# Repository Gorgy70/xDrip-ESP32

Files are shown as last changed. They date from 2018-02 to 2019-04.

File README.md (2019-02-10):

# xDrip-ESP32
Проект с функциональностью wixel-xDrip, xBridge2 и Parakeet на контроллере ESP32<br>
<br>

Данный проект является развитием проекта Parakeet-A (https://github.com/Gorgy70/parakeet-A) и основан на следующих проектах:<br>
1. Parakeet от Jamorham (https://jamorham.github.io, https://github.com/jamorham/wixel-xDrip)<br>
2. XDrip от Emma Black (http://stephenblackwasalreadytaken.github.io/xDrip, https://github.com/StephenBlackWasAlreadyTaken/xDrip)<br>
3. CC2500-Project от Don Browne (https://github.com/brownedon/CC2500-Project)<br>
<br>
<br>
<b>Сборка прибора:</b><br>
<br>
Для сборки прибора необходимы следующие компоненты:<br>
1. Контроллер ESP-32. <br>
Я использую модуль ESP32-WROOM:<br>
https://www.aliexpress.com/item/ESP-32S-ESP-WROOM-32-ESP32-ESP-32-Bluetooth-and-WIFI-Dual-Core-CPU-with-Low/32826634234.html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
<br>
2. Радиомодуль на базе чипа Texas Instruments CC2500 с усилителем слабого сигнала.<br>
https://www.aliexpress.com/item/CC2500-PA-LNA-Romote-Wireless-Module-CC2500-SI4432-For-RC-Quadcopter-Helicopter-Multirotor-Model-Parts/32740098548.html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
<br>
3. Модуль контроля заряда батареи.<br>
4. Аккумулятор 3.7 В.<br>
5. Стаблизатор, для понижения напряжения до 3.3В:
https://www.aliexpress.com/item/Free-Shipping-Hot-Sale-Smart-Electronics-Integrated-Circuit-AP7361-15FGE-7-IC-REG-LDO-1-5V/32584383940.html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
<br>
6. Светодиоды, резисторы и конденсаторы в соответствии с печатной платой.<br>
<br>
<b>Установка поддержки ESP-32 в Arduino Studio:</b><br>
<br>
https://github.com/espressif/arduino-esp32/blob/master/docs/arduino-ide/windows.md<br>
<br>
<b>Настройка библиотеки ESP32</b><br>
<br>
При использовании свежих версий SDK тактовая частота контроллера устанавливается в Arduino IDE.
Также необходимо установить параметр "Partition Scheme" в значение "No OTA (Large APP)". В противном случае компиляция скэтча завершится с ошибкой.
<br>
<b>Загрузка прошивки в контроллер</b><br>
<br>
Для загрузки прошивки в контроллер необходимо подключить к плате адаптер USB-TTL используя контакты для программирования<br>
Чтобы активировать режим прошивки контроллера необходимо замкнуть контакт IO0 контроллера на землю и перегрузить контроллер кратковременным замыканием контакта EN на землю.<br>
Если не удается загрузит прошивку на скорости 921600 - попробуйте понизить скорость до 115200.<br>
После удачной загрузки прошивки убрать перемычку с контакта IO0 на землю и перегрузить контроллер.<br>
<br>
<br>
<b>Настройка прибора:</b><br>
<br>
Первые 2 минуты после включения прибор находится в режиме настройки.<br>
В этом режиме прибор запускает WiFi точку доступа c именем "Parakeet" и без пароля.<br>
Для конфигурации прибора необходимо подключиться к этой точке доступа, запустить интернет браузер и в адресной строке ввести адрес http://192.168.70.1<br>
В открывшейся форме параметров можно настроить следующие параметры:<br>
<ul style="list-style-type:disc">
  <li>Код трансмиттера Dexcom</li>
  <li>Цифровой код для работы с облачным сервисом</li>
  <li>Адрес облачного сервиса</li>
  <li>Имя точки доступа WiFi для передачи данных в интернет. Если вы не планируете использовать WiFi оставьте это поле пустым.</li>
  <li>Пароль для точки доступа WiFi</li>
  <li>Формат обмена по BlueTooth (без BlueTooth, xDrip, xBridge)</li>
  <li>Признак работы прибора с мобильной сетью</li>
  <li>APN вышего мобильного оператора</li>
</ul>
После заполнения всех необходимых полей нажмите кнопку "Save".<br>
В случае использования прибора в режиме xBridge код трансмиттера Dexcom можно установить с помощью программы xDrip+ на вашем мобильном телефоне.<br>
В случае использования прибора с поддержкой мобильной сети, некоторые настройки можно изменять с помощью СМС на номер симкарты, установленной в прибор.<br>
Список обрабатываемых СМС:<br>
<ul style="list-style-type:disc">
  <li>TRANSMIT <Код трансмиттера Dexcom> - установить код трансмиттера Dexcom</li>
  <li>PWD <цифровой код> - установить цифровой код</li>
  <li>HTTP <адрес облачного сервиса> - установить адрес облачного сервиса</li>
  <li>APN <APN вашего мобильного оператора> - установить APN мобильного оператора</li>
  <li>SETTINGS - узнать текущие настройки. Текущие настройки будут присланы несколькими СМС-сообщениями</li>
  <li>REBOOT - перегрузить прибор</li>
  <li>VERSION - узнать версию прошивки</li>
  <li>USE_GSM <флаг>- включить/выключить мобильную связь. В качестве флага могут использоваться символы 0,N,n для выключения мобильной связи и символы 1,Y,y для включения.
Следует заметить, что при выключенной мобильной связи прибор не сможет принять СМС.</li>
  <li>BT_FORMAT <флаг> - установка формата обмена данными по BlueTooth. Возможные значения флага: 0,N,n - без BlueTooth; 1,D,d - xDrip; 2,B,b - xBridge</li>
</ul>
<br>
<b>Привязка прибора к программе xDrip+ по протоколу BlueTooth:</b><br>
<br>
Алгоритм работы прибора разработан таким образом, что BlueTooth включается только после того как прибор поймает сигнал от трансмиттера.<br>
Для привязки прибора к программе xDrip+ по протоколу BlueTooth необходимо выполнить следующие действия:<br>
1. Включить прибор.<br>
2. При необходимости настроить параметры прибора<br>
3. Дождаться сигнала с трансмиттера. Во время ожидания сигнала с трансмиттера прибор коротко мигает желтым светодиодом.<br>
4. После пойманного сигнала, прибор отправит данные в интернет (если такой режим работы настроен) и будет ждать 45 секунд соединения с программой xDrip+
по протоколу BlueTooth. При этом будет непрерывно гореть желтый светодиод.<br>
5. В течении 45 секунд в программе xDrip+  необходимо произвести BlueTooth Scan и выбрать прибор из списка найденных.<br>

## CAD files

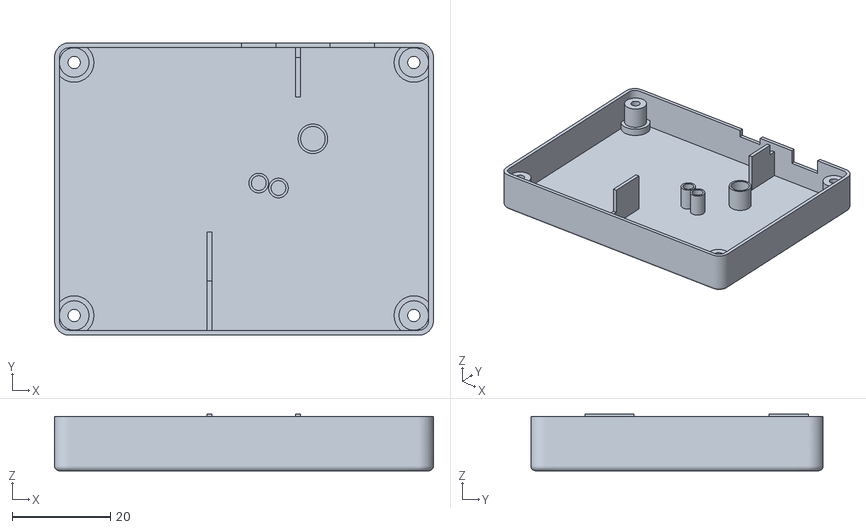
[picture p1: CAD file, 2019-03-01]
xDrip32-3G-Top4.stl
77.0 x 59.4 x 11.5

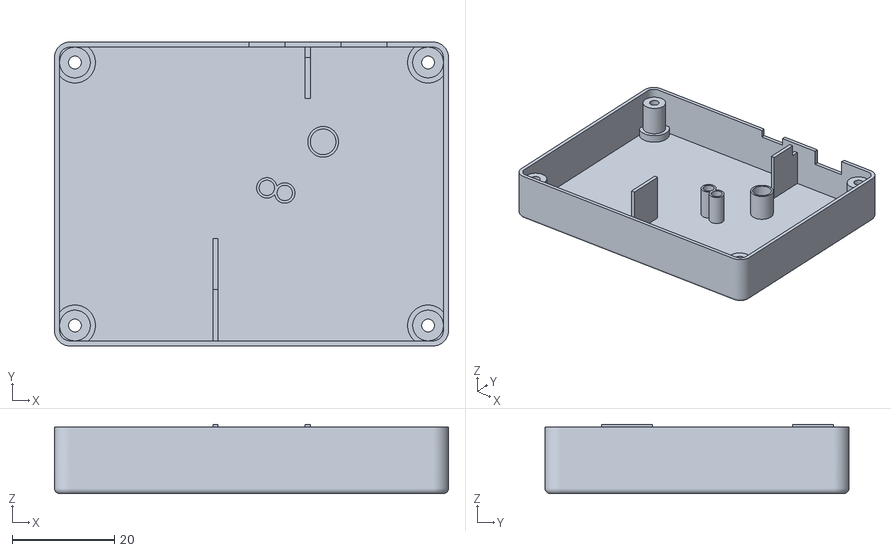
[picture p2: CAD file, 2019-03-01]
xDrip32-3G-Top5.stl
77.0 x 59.4 x 13.5

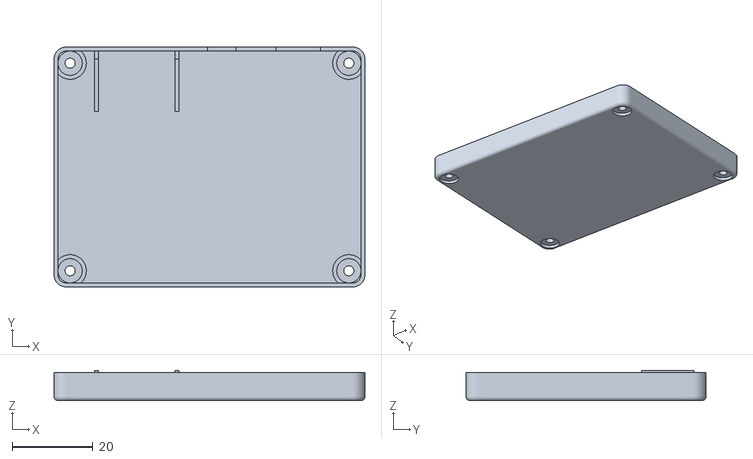
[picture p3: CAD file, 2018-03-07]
xDrip32-WiFi-Top2.stl
77.0 x 59.4 x 7.50

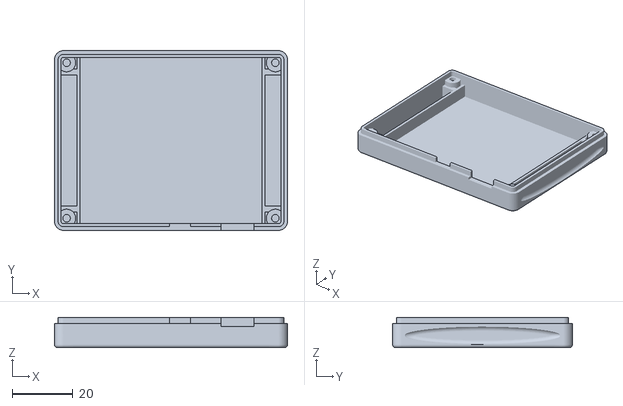
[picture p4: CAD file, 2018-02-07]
xDrip32-WiFi-Bottom3.stl
77.0 x 59.4 x 10.00

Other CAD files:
xDrip32-3G-Bottom3.stl

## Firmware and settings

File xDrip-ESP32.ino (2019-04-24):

 
#define DEBUG
//#define INT_BLINK_LED
#define EXT_BLINK_LED
#define GSM_MODEM
//#define MODEM_SLEEP_DTR
//#define PCB_V1
//#define PCB_V2
#define PCB_V3
//#define USE_FREQEST    
#define DEEP_SLEEP_MODE
#define BT_PAIRING 

#include "driver/gpio.h"
#include "soc/rtc_cntl_reg.h"
#include "driver/rtc_cntl.h"
#include "soc/rtc.h"
#include "rom/rtc.h"
#include "SPI.h"
#include "EEPROM.h"
#include "WiFi.h"
#include "HTTPClient.h"
#include "bt.h"
#include "nvs_flash.h"
#include <WebServer.h>
//#include <BLEDevice.h>
//#include <BLEServer.h>
//#include <BLEUtils.h>
//#include <BLE2902.h>
//#include "bta_api.h"

#include "esp_system.h"
#include "esp_wifi.h"
#include "esp_wifi_types.h"
#include "esp_gap_ble_api.h"
#include "esp_gatts_api.h"
#include "esp_bt_defs.h"
#include "esp_bt_main.h"
#include "esp_sleep.h"
#include "esp_deep_sleep.h"

#include "cc2500_REG.h"
#include "webform.h"

extern "C" {
uint8_t temprature_sens_read(); 
}

#define VERSION_NUM "1.6.3"

#define LEN_PIN    GPIO_NUM_5             // Цифровой канал, к которму подключен контакт LEN (усилитель слабого сигнала) платы CC2500 (Предыдущее значение 17).
#define BAT_PIN    GPIO_NUM_34            // Аналоговый канал для измерения напряжения питания
#ifdef EXT_BLINK_LED
  #define RED_LED_PIN    GPIO_NUM_16
  #define YELLOW_LED_PIN GPIO_NUM_17
#endif

#define SCK_PIN   GPIO_NUM_22
#define MISO_PIN  GPIO_NUM_21
#define MOSI_PIN  GPIO_NUM_23
#define SS_PIN    GPIO_NUM_18 // Предыдущее значение 5
#ifdef PCB_V1
  #define GDO0_PIN   GPIO_NUM_19            // Цифровой канал, к которму подключен контакт GD0 платы CC2500
#endif
#ifdef PCB_V2
  #define GDO0_PIN   GPIO_NUM_19            // Цифровой канал, к которму подключен контакт GD0 платы CC2500
#endif
#ifdef PCB_V3
  #define GDO0_PIN   GPIO_NUM_15            // Цифровой канал, к которму подключен контакт GD0 платы CC2500
#endif
#ifdef GSM_MODEM
  #define RX_PIN  GPIO_NUM_25
  #define TX_PIN  GPIO_NUM_26
#ifdef PCB_V1
  #define DTR_PIN    GPIO_NUM_13
#endif
#ifdef PCB_V2
  #define DTR_PIN    GPIO_NUM_14
#endif
#ifdef PCB_V3
  #define DTR_PIN    GPIO_NUM_14
#endif
  #define RST_PIN    GPIO_NUM_27
#endif

#define NUM_CHANNELS        (4)       // Кол-во проверяемых каналов
#define FIVE_MINUTE         300000    // 5 минут
#define TWO_MINUTE          120000    // 2 минуты
#define WAKEUP_BT_TIME      54000     // Время необходимое для просыпания прибора c BT
#define WAKEUP_NON_BT_TIME  5000      // Время необходимое для просыпания прибора без BT
#define SPI_TIME_OUT        1000

#define RADIO_BUFFER_LEN 200 // Размер буфера для приема данных от радиомодуля
#ifdef GSM_MODEM
  #define SERIAL_BUFFER_LEN 200 // Размер буфера для приема данных от GSM модема
#endif

#define GSM_DELAY 200         // Задержка между командами модема

// assuming that there is a 10k ohm resistor between BAT+ and BAT_PIN, and a 27k ohm resistor between BAT_PIN and GND
#define  VREF                 3.3 // Опорное напряжение для аналогового входа
#define  VMAX                 4.2  // Максимальное напряжение батареи
#ifdef GSM_MODEM
#define  VMIN                 3.2  // Минимальное напряжение батареи при использовании ГСМ модема
#else
#define  VMIN                 3.0  // Минимальное напряжение батареи
#endif
#define  R1                   10   // Резистор делителя напряжения между BAT+ и BAT_PIN (кОм)
#define  R2                   27   // Резистор делителя напряжения между BAT_PIN и GND (кОм)
#define  ANALOG_RESOLUTION    4095 // Масимальное значение на аналоговом входе. Ио умолчанию 12 бит 
int      BATTERY_MAXIMUM  =   VMAX*ANALOG_RESOLUTION*R2/(R1+R2)/VREF ; //950 4.2V 1023*4.2*27(27+10)/3.3
int      BATTERY_MINIMUM  =   VMIN*ANALOG_RESOLUTION*R2/(R1+R2)/VREF ; //678 3.0V 1023*3.0*27/(27+10)/3.3

#define my_webservice_url    "http://parakeet.esen.ru/receiver.cgi"
#define my_webservice_reply  "!ACK"
#define my_user_agent        "parakeet-ESP32"
#define my_password_code     "12543"
#define my_gprs_apn   "internet.mts.ru"

#define my_wifi_ssid         "ssid"
#define my_wifi_pwd          "password"

#define GATTS_SERVICE_UUID_XDRIP     0xFFE0  // UID сервиса BLE
#define GATTS_CHAR_UUID_XDRIP        0xFFE1  // UID значения BLE
#define GATTS_NUM_HANDLE_TEST_ON     4     
#define SERVICE_UUID_XDRIP = "0000ffe0-0000-1000-8000-00805f9b34fb";
#define CHAR_UUID_XDRIP = "0000ffe1-0000-1000-8000-00805f9b34fb";
  
/* maximum value of a characteristic */
#define GATTS_CHAR_VAL_LEN_MAX 0xFF

// defines the xBridge protocol functional level.  Sent in each packet as the last byte.
#define DEXBRIDGE_PROTO_LEVEL (0x01)

portMUX_TYPE mux = portMUX_INITIALIZER_UNLOCKED;

unsigned long dex_tx_id;
char transmitter_id[] = "ABCDE";

IPAddress local_IP(192,168,70,1);
IPAddress gateway(192,168,70,1);
IPAddress subnet(255,255,255,0);
uint8_t   wifi_mac[6];

//WiFiServer server(80);
//WiFiClient client;
WebServer server2(80);


SPIClass SPIclient(VSPI);

#ifdef GSM_MODEM
  #define ERROR_STR "ERROR"
//  SoftwareSerial mySerial(RX_PIN, TX_PIN); // RX, TX
  HardwareSerial mySerial(2);
#endif
  
unsigned long web_server_start_time;

unsigned long packet_received = 0;
unsigned long cc2500_start_time;
int current_channel;
boolean packet_catched;
boolean len_pin_low;
volatile byte gdo0_status;
byte loop_count;
volatile boolean new_dex_id_recieved;
volatile boolean ack_recieved;
volatile boolean ble_connected;

#ifdef USE_FREQEST
RTC_DATA_ATTR byte fOffset[NUM_CHANNELS] = { 0x00, 0x00, 0x00, 0x00 };
#else
byte fOffset[NUM_CHANNELS] = { 0xE4, 0xE3, 0xE2, 0xE2 };
#endif
byte nChannels[NUM_CHANNELS] = { 0, 100, 199, 209 };
unsigned long waitTimes[NUM_CHANNELS] = { 0, 550, 550, 550 };
char version_str[15];

byte sequential_missed_packets = 0;
byte wait_after_time = 100;
unsigned long next_time = 0; // Время ожидания следующего пакета на канале 0
unsigned long catch_time = 0; // Время последнего пойманного пакета (приведенное к пакету на канале 0)

byte misses_until_failure = 2;                                                   //
// after how many missed packets should we just start a nonstop scan?                               //
// a high value is better for conserving batter life if you go out of wixel range a lot             //
// but it could also mean missing packets for MUCH longer periods of time                           //
// a value of zero is best if you dont care at all about battery life                               //

byte wifi_wait_tyme = 100; // Время ожидания соединения WiFi в секундах
byte default_bt_format = 0; // Формат обмена по протколу BlueTooth 0 - None 1 - xDrip, 2 - xBridge
unsigned int battery_milivolts;
int battery_percent;
boolean low_battery = false;
unsigned int wake_up_time; // За сколько времени до ожидаемого сигнала надо проснуться

#ifdef GSM_MODEM
  boolean gsm_availible = false; // Доступность связи GSM
  boolean modem_availible = false; // Доступность модема на порту
  boolean internet_availible = false; // Флаг подключения мобильного интернета
  boolean modem_sleeping = false; // Модем находится в режиме сна
  char SerialBuffer[SERIAL_BUFFER_LEN]; // Буффер для работы GSM модемом
#endif

char radio_buff[RADIO_BUFFER_LEN]; // Буффер для чтения данных и прочих нужд

volatile uint16_t ble_gatts_if = ESP_GATT_IF_NONE;
uint16_t ble_conn_id;
uint16_t ble_attr_handle;

esp_gatt_srvc_id_t ble_service;
esp_bt_uuid_t ble_character;
esp_bt_uuid_t ble_descr_uuid;

// Коды ошибок мигают лампочкой в двоичной системе
// 1 (0001) - Нет модключения к WiFi
// 2 (0010) - Облачная служба не отвечает
// 3 (0011) - Облачная служба возвращает ошибку
// 4 (0100) - Неверный CRC в сохраненных настройках. Берем настройки по умолчанию
// 5 (0101) - Не подключен модем.
// 6 (0110) - Нет мобильной связи
// 7 (0111) - Нет мобильного интернета

/* value range of a attribute (characteristic) */
uint8_t attr_str[] = {0x00};
esp_attr_value_t gatts_attr_val =
{
    .attr_max_len = GATTS_CHAR_VAL_LEN_MAX,
    .attr_len     = sizeof(attr_str),
    .attr_value   = attr_str,
};

/* service uuid */
static uint8_t service_uuid128[32] = {
    /* LSB <--------------------------------------------------------------------------------> MSB */
    //first uuid, 16bit, [12],[13] is the value
    0xfb, 0x34, 0x9b, 0x5f, 0x80, 0x00, 0x00, 0x80, 0x00, 0x10, 0x00, 0x00, 0xAB, 0xCD, 0x00, 0x00,
};

static esp_ble_adv_data_t ble_adv_data = {
    .set_scan_rsp = false,
    .include_name = true,
    .include_txpower = true,
    .min_interval = 0x20,
    .max_interval = 0x40,
    .appearance = 0x00,
    .manufacturer_len = 0,
    .p_manufacturer_data =  NULL,
    .service_data_len = 0,
    .p_service_data = NULL,
    .service_uuid_len = 16,
    .p_service_uuid = service_uuid128,
    .flag = (ESP_BLE_ADV_FLAG_GEN_DISC | ESP_BLE_ADV_FLAG_BREDR_NOT_SPT),
};

esp_ble_adv_params_t ble_adv_params;


typedef struct _Dexcom_packet
{
  byte len;
  unsigned long dest_addr;
  unsigned long src_addr;
  byte port;
  byte device_info;
  byte txId;
  unsigned int raw;
  unsigned int filtered;
  byte battery;
  byte unknown;
  byte checksum;
  byte RSSI;
  byte LQI2;
} Dexcom_packet;

Dexcom_packet Pkt;

typedef struct _RawRecord
{
  byte size; //size of the packet.
  byte cmd_code; // code for this data packet.  Always 00 for a Dexcom data packet.
  unsigned long  raw;  //"raw" BGL value.
  unsigned long  filtered; //"filtered" BGL value 
  byte dex_battery;  //battery value
  byte my_battery; //xBridge battery value
  unsigned long  dex_src_id;   //raw TXID of the Dexcom Transmitter
  //int8  RSSI; //RSSI level of the transmitter, used to determine if it is in range.
  //uint8 txid; //ID of this transmission.  Essentially a sequence from 0-63
  byte function; // Byte representing the xBridge code funcitonality.  01 = this level.
} RawRecord;

typedef struct _parakeet_settings
{
  unsigned long dex_tx_id;     //4 bytes
  char http_url[56];
  char password_code[6];
  char wifi_ssid[17];
  char wifi_pwd[18];
  byte bt_format;
  byte use_gsm;
  char gsm_apn[31];
  unsigned long checksum; // needs to be aligned

} parakeet_settings;

parakeet_settings settings;

typedef struct _bad_data_element
{
  boolean has_data;
  char    data[21];
} bad_data_element;

bad_data_element bad_data[NUM_CHANNELS];

char SrcNameTable[32] = { '0', '1', '2', '3', '4', '5', '6', '7',
                          '8', '9', 'A', 'B', 'C', 'D', 'E', 'F',
                          'G', 'H', 'J', 'K', 'L', 'M', 'N', 'P',
                          'Q', 'R', 'S', 'T', 'U', 'W', 'X', 'Y'
                        };


void dexcom_src_to_ascii(unsigned long src, char addr[6]) {
  addr[0] = SrcNameTable[(src >> 20) & 0x1F];
  addr[1] = SrcNameTable[(src >> 15) & 0x1F];
  addr[2] = SrcNameTable[(src >> 10) & 0x1F];
  addr[3] = SrcNameTable[(src >> 5) & 0x1F];
  addr[4] = SrcNameTable[(src >> 0) & 0x1F];
  addr[5] = 0;
}


unsigned long getSrcValue(char srcVal) {
  byte i = 0;
  for (i = 0; i < 32; i++) {
    if (SrcNameTable[i] == srcVal) break;
  }
  return i & 0xFF;
}

unsigned long asciiToDexcomSrc(char addr[6]) {
  unsigned long src = 0;
  src |= (getSrcValue(addr[0]) << 20);
  src |= (getSrcValue(addr[1]) << 15);
  src |= (getSrcValue(addr[2]) << 10);
  src |= (getSrcValue(addr[3]) << 5);
  src |= getSrcValue(addr[4]);
  return src;
}

byte bit_reverse_byte (byte in)
{
    byte bRet = 0;
    if (in & 0x01)
        bRet |= 0x80;
    if (in & 0x02)
        bRet |= 0x40;
    if (in & 0x04)
        bRet |= 0x20;
    if (in & 0x08)
        bRet |= 0x10;
    if (in & 0x10)
        bRet |= 0x08;
    if (in & 0x20)
        bRet |= 0x04;
    if (in & 0x40)
        bRet |= 0x02;
    if (in & 0x80)
        bRet |= 0x01;
    return bRet;
}

void bit_reverse_bytes (byte * buf, byte nLen)
{
    byte i = 0;
    for (; i < nLen; i++)
    {
        buf[i] = bit_reverse_byte (buf[i]);
    }
}

unsigned long dex_num_decoder (unsigned int usShortFloat)
{
    unsigned int usReversed = usShortFloat;
    byte usExponent = 0;
    unsigned long usMantissa = 0;
    bit_reverse_bytes ((byte *) & usReversed, 2);
    usExponent = ((usReversed & 0xE000) >> 13);
    usMantissa = (usReversed & 0x1FFF);
    return usMantissa << usExponent;
}

void clearSettings()
{
  memset (&settings, 0, sizeof (settings));
  settings.dex_tx_id = asciiToDexcomSrc (transmitter_id);
  dex_tx_id = settings.dex_tx_id;
  sprintf(settings.http_url, my_webservice_url);
  sprintf(settings.password_code, my_password_code);
  sprintf(settings.wifi_ssid, my_wifi_ssid);
  sprintf(settings.wifi_pwd, my_wifi_pwd);
  sprintf(settings.gsm_apn, my_gprs_apn);
  settings.bt_format = default_bt_format;
  settings.checksum = 0;
}

unsigned long checksum_settings()
{
  char* flash_pointer;
  unsigned long chk = 0x12345678;
  byte i;
  //   flash_pointer = (char*)settings;
  flash_pointer = (char*)&settings;
  for (i = 0; i < sizeof(parakeet_settings) - 4; i++)
  {
    chk += (flash_pointer[i] * (i + 1));
    chk++;
  }
  return chk;
}

void saveSettingsToFlash()
{
  char* flash_pointer;
  byte i;

  EEPROM.begin(sizeof(parakeet_settings));
  
  settings.checksum = checksum_settings();
  flash_pointer = (char*)&settings;
  for (i = 0; i < sizeof(parakeet_settings); i++)
  {
    EEPROM.write(i,flash_pointer[i]);
  }
  EEPROM.commit();
//  EEPROM.put(0, settings);
}

void loadSettingsFromFlash()
{
  char* flash_pointer;
  byte i;

  EEPROM.begin(sizeof(parakeet_settings));
  flash_pointer = (char*)&settings;
  for (i = 0; i < sizeof(parakeet_settings); i++)
  {
    flash_pointer[i] = EEPROM.read(i);
  }
  
//  EEPROM.get(0, settings);
  dex_tx_id = settings.dex_tx_id;
  if (settings.checksum != checksum_settings()) {
    clearSettings();
#ifdef INT_BLINK_LED
    blink_sequence("0100");
#endif
#ifdef EXT_BLINK_LED
    blink_sequence_red("0100");
#endif
  }
}

#ifdef EXT_BLINK_LED
void blink_sequence_red(const char *sequence) {
  byte i;

  digitalWrite(YELLOW_LED_PIN, HIGH);
  digitalWrite(RED_LED_PIN, LOW);
  delay(500); 
  for (i = 0; i < strlen(sequence); i++) {
    digitalWrite(RED_LED_PIN, HIGH);
    switch (sequence[i]) {
      case '0': 
        delay(200);
        break;
      case '1': 
        delay(1000);
        break;
      default:
        delay(2000);
        break;
    }
    digitalWrite(RED_LED_PIN, LOW);
    delay(500); 
  }  
  digitalWrite(YELLOW_LED_PIN, LOW);
}

void blink_yellow_led_quarter() {  // Blink quarter seconds
  if ((millis() / 250) % 2) {
    digitalWrite(YELLOW_LED_PIN, HIGH);
  } else
  {
    digitalWrite(YELLOW_LED_PIN, LOW);
  }
}

void blink_yellow_led_half() {  // Blink half seconds
  if ((millis() / 500) % 2) {
    digitalWrite(YELLOW_LED_PIN, HIGH);
  } else
  {
    digitalWrite(YELLOW_LED_PIN, LOW);
  }
}

void blink_red_led_quarter() {  // Blink quarter seconds
  if ((millis() / 250) % 2) {
    digitalWrite(RED_LED_PIN, HIGH);
  } else
  {
    digitalWrite(RED_LED_PIN, LOW);
  }
}

void blink_red_led_quarter2() {  // Blink quarter seconds
  if ((millis() / 250) % 2) {
    digitalWrite(RED_LED_PIN, LOW);
  } else
  {
    digitalWrite(RED_LED_PIN, HIGH);
  }
}

void blink_red_led_half() {  // Blink half seconds
  if ((millis() / 500) % 2) {
    digitalWrite(RED_LED_PIN, HIGH);
  } else
  {
    digitalWrite(RED_LED_PIN, LOW);
  }
}

void blink_red_led_half2() {  // Blink half seconds
  if ((millis() / 500) % 2) {
    digitalWrite(RED_LED_PIN, LOW);
  } else
  {
    digitalWrite(RED_LED_PIN, HIGH);
  }
}
#endif
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
void loop() {
  unsigned long current_time;
  boolean packet_on_board;
  int old_channel;
  byte packet_len;
  uint8_t freqest;
  int rssi;
  byte gdo0_status2;

// Первые две минуты работает WebServer на адресе 192.168.70.1 для конфигурации устройства
  if (web_server_start_time > 0) {
#ifdef EXT_BLINK_LED    
    blink_red_led_half();
#endif
/*
    client = server.available();
    if (client) {
      HandleWebClient();
    }
*/    
    server2.handleClient();
    delay(1);
//    if ((millis() - web_server_start_time) > TWO_MINUTE && !server.hasClient()) {
    if ((millis() - web_server_start_time) > TWO_MINUTE && !server2.client()) {
      server2.stop();
      WiFi.softAPdisconnect(true);
      web_server_start_time = 0;  
#ifdef DEBUG
      Serial.println("Configuration mode is done!");
#endif
/*
      if (settings.bt_format == 0) {
        wake_up_time = WAKEUP_NON_BT_TIME;
      }
      else {
        wake_up_time = WAKEUP_BT_TIME;        
      }
*/      
      if (settings.bt_format == 2 && dex_tx_id == 10858926) sendBeacon();
//      PrepareBlueTooth();
//      delay(500);
      mesure_battery();        
#ifdef GSM_MODEM
      init_GSM(true);
#endif
    }
    return;
  }
  
// Ловим сигнал от Декскома
//  delay(1);
  packet_on_board = false;
  
  current_time = millis();

  if (len_pin_low) {
    digitalWrite(LEN_PIN, HIGH); // Включаем усилитель слабого сигнала
// Включаем усилитель слабого сигнала  
    len_pin_low = false;
  } 

  old_channel = current_channel;
  if (current_channel < 0) {
    current_channel = 0;
    enable_WDT(1);
  }
  if (current_channel > 0 && current_time - cc2500_start_time > waitTimes[current_channel]) {
    current_channel++;
    if (current_channel > 3) {
      current_channel = 3;
      packet_on_board = true;
#ifdef DEBUG
      Serial.println("Chanels end. Signal not catched");
#endif
    }
  }  

  if (current_channel != old_channel) {  
    cc2500_start_time = current_time;
    swap_channel(nChannels[current_channel], fOffset[current_channel]);
    bad_data[current_channel].has_data = false;    
#ifdef DEBUG
    Serial.print("Chanel = ");
    Serial.print(nChannels[current_channel]);
    Serial.print(" Time = ");
    Serial.println(cc2500_start_time);
#endif
  }

/*   
#ifdef INT_BLINK_LED
  blink_builtin_led_quarter();
#endif
#ifdef EXT_BLINK_LED
  if (dex_tx_id == 10858926 || dex_tx_id == 0)   // ABCDE
  {
    blink_yellow_led_half();
    if (low_battery) {
      blink_red_led_half2();
    }
  } else
  {
    blink_yellow_led_quarter();
    if (low_battery) {
      blink_red_led_quarter2();
    }
  }  
#endif
*/
  if (current_channel == 0) {
    feed_WDT();
    light_sleep(100);
    delay(1);
    packet_on_board = ReadStatus(RXBYTES);   
#ifdef EXT_BLINK_LED
    loop_count++;
    if (loop_count > 10) {
      digitalWrite(YELLOW_LED_PIN, HIGH);
      if (low_battery) 
        digitalWrite(RED_LED_PIN, HIGH);
      loop_count = 0;
    } 
    else {
      digitalWrite(YELLOW_LED_PIN, LOW);
      digitalWrite(RED_LED_PIN, LOW);
    }
// Зажигаем желтую ламочку
#endif
  } 
  else {
    gdo0_status2 = gdo0_status;
    if (gdo0_status2 > 0) packet_on_board = true;
//    packet_on_board |= gdo0_status;
  }
  
  if (packet_on_board) {
    if (current_channel == 0) disable_WDT();
#ifdef DEBUG
    Serial.println("Packet on board!");
#endif
    unsigned long t1 = millis();
    while (digitalRead(GDO0_PIN) == HIGH) {
      if (millis() - t1 > SPI_TIME_OUT) {
#ifdef DEBUG
        Serial.println("packet_on_board SPI timeout"); 
#endif
        break;
      }
    }
  } else return; // Нет сигнала от декскома - выходим из цикла

#ifdef INT_BLINK_LED
  digitalWrite(LED_BUILTIN, LOW);
#endif
#ifdef EXT_BLINK_LED
  digitalWrite(YELLOW_LED_PIN, LOW);
  digitalWrite(RED_LED_PIN, LOW);
#endif

  packet_len = ReadRadioBuffer(current_channel);
#ifdef USE_FREQEST
  if (packet_len == 0 || packet_len == 21) {
    freqest = ReadStatus(FREQEST);
    fOffset[current_channel] += freqest;
//    fOffset[current_channel] = freqest;
#ifdef DEBUG
    Serial.print("Offset:");
    Serial.println(fOffset[current_channel], HEX);
#endif
  }
#endif
  if (Pkt.src_addr == dex_tx_id) {
#ifdef DEBUG
    Serial.print("gdo0_status = ");
    Serial.println(gdo0_status2);
    Serial.print("Catched.Ch=");
    Serial.println(nChannels[current_channel]);
    Serial.print("Signal Power = ");
    if (Pkt.RSSI > 127) rssi = (Pkt.RSSI - 256) / 2 - 73;
    else rssi = Pkt.RSSI / 2 - 73;
    Serial.println(rssi);
    Serial.print("Signal Quality = ");
    Serial.println(Pkt.LQI2);
#endif
    catch_time = current_time - 500 * current_channel; // Приводим к каналу 0
    next_time = catch_time + FIVE_MINUTE;
    packet_catched = true;
    digitalWrite(LEN_PIN, LOW); // Выключаем усилитель слабого сигнала
    SendStrobe(SIDLE);  // Переводим приемник в режим ожидания
    SendStrobe(SFRX);  // Очищаем буфер вхоядщих данных
  } 
  else {
    current_channel++;
    if (current_channel > 3) {
      current_channel = 0;
    }
    cc2500_start_time = current_time;
    swap_channel(nChannels[current_channel], fOffset[current_channel]);
    bad_data[current_channel].has_data = false;    
#ifdef DEBUG
    Serial.print("channel index = ");
    Serial.println(current_channel);
    Serial.print("gdo0_status = ");
    Serial.println(gdo0_status2);
    Serial.print("Chanel = ");
    Serial.print(nChannels[current_channel]);
    Serial.print(" Time = ");
    Serial.println(cc2500_start_time);
#endif
  }
  portENTER_CRITICAL(&mux);
  gdo0_status = 0;
  portEXIT_CRITICAL(&mux);

  if (!packet_catched && current_channel == 0)
    check_bad_data();
  if (packet_catched)
  {
    mesure_battery();
//    delay(500);
    if (!print_wifi_packet () && settings.use_gsm) {
//  - Отправить пакет по модему, если он не ушел по ВайФай    
#ifdef GSM_MODEM
      gsm_wake_up(); // Будим GSM-модем
      if (modem_availible) {
        if (!print_modem_packet()) {
          init_GSM(false);
          if (internet_availible) {
            print_modem_packet();
          }  
        }
      }  
#endif      
    }
//  - Отправить пакет по BlueTooth
    print_bt_packet();
  } 
  else if (current_channel == 0) {
    sendBeacon();
    mesure_battery();
  }
#ifdef GSM_MODEM
  if (packet_catched || current_channel == 0) 
    check_sms();
#endif
  if (!packet_catched && current_channel == 0) 
    enable_WDT(1);
  
  if (packet_catched) {
    esp32_goto_sleep();    
  }
}

void gdo0_pin_up() {
  try {
    portENTER_CRITICAL_ISR(&mux);
    gdo0_status = 1;  
    portEXIT_CRITICAL_ISR(&mux);
  } catch (...) {
#ifdef DEBUG
    Serial.println("Error in ISRR");
#endif
  }  
}

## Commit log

2017-08-31 Первый вариант проекта без BT. Без спящего режима. Без тестирования.
2017-09-06 Добавлена функциональность BT Добавлены поля настроек для GSM
2017-09-07 Добавлено управление внешними светодиодами
2017-09-11 Первая версия отлаженного прложения. Добавлен спящий режим.
2017-09-11 Мелкие исправления Добавлено чтение ID трансмиттера c телефона в режиме xBridge
    [xDrip-ESP32.ino]
2017-09-12 Исправлена ошибка в чтении пакета смены ID трансмитера
    [xDrip-ESP32.ino]
2017-09-13 Небольшая оптимизация алгоритма спящего режима
2017-10-15 Назначение контатов. Измерение напряжения батареи
    1. Изменено назначение входов/выходов контроллера в соответствии с монтажной схемой
    2. Отлажена процедура измерения напряжения аккумулятора.
2017-10-16 Добавлен функционал работы GSM-модемом
2017-10-17 Модем можно подключать к любым IO
2017-10-19 Добалено обработка сообщения ERROR при работе с модемом
    [xDrip-ESP32.ino]
2017-10-19 Добавлена инициализация RST_PIN
2017-10-31 Добавлен текст ReadMe
2017-10-31 Добавлена информация в ReadMe
2017-10-31 Исправление ошибок
2017-10-31 Добавлено форматирование текста
2017-11-01 Добавлено описание режима настройки
2017-11-18 Отладка проекта
2017-11-19 Новый алгоритм работы с радиосигналом
2017-11-20 Изменение в read.me
2017-11-20 Небольшие изменения радиопараметров
2017-11-20 Добавлена печатная плата
2017-11-20 Добавлен алгоритм подстройки частоты
2017-11-21 Тонкая настройка параметров радиомодуля
2017-11-26 Исправлена ошибка при работе с ГСМ-модемом
    [xDrip-ESP32.ino]
2017-11-28 В имя BT добавлены цифры MAC Исправлена ошибка WiFi
    [xDrip-ESP32.ino]
2017-11-28 Отлажен прием СМС
2017-11-29 Исправлена ошибка в цикле Мелкие оптимизации
    [xDrip-ESP32.ino]
2017-12-15 Изменен алгоритм ожидания сигнала Добавлены 3-D модели корпусов
    [xDrip32-3G-Bottom.stl, xDrip32-3G-Top.stl, xDrip32-WiFi-Bottom3.stl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]
2017-12-15 Исправлены ошибки в новом алгоритме работы
    [xDrip-ESP32.ino]
2017-12-16 Небольшие изменения в цветовой индикации
2017-12-18 Отладка передачи данных по WiFi и BT
2017-12-19 Добавлен режим легкого сна
2017-12-23 Уменьшена частота поцессора до 80 МГц Уменьшена мощность BT до - 11 дб.
2017-12-27 Добавлен Watch Dog таймер
2017-12-28 Добавлен защищенный режим прерываний
2018-01-07 Мелкие исправления Добавлен отладочный вывод в функции выключения BT
    [xDrip-ESP32.ino]
2018-01-12 Исправлена ошибка в обработке входящих пакетов БТ
    [xDrip-ESP32.ino]
2018-01-24 Выложена новая версия печатной платы
2018-01-26 Описание настройки библиотеки ESP32 в read.me
2018-01-26 Добавлено описание настройки BlueTooth в read.me
2018-01-26 Исправление орфографических ошибок в read.me
2018-01-30 Правка корпуса
    [xDrip32-3G-Bottom.stl]
2018-02-02 Доработка корпуса и добавление информации в read.me
    [xDrip32-3G-Bottom.stl, xDrip32-WiFi-Bottom3.stl]
2018-02-06 Добавлен еще один вариант срабатывания строржевого пса
2018-02-09 Установка параметров радиомодуля при каждом старте системы Изменение заголовка вэб-формы настройки парметров
2018-02-12 Добавлены новые СМС для настройки параметров Добавлена версия прошивки
2018-02-13 В режиме отключения GSM мобильная связь отключена Исправлена процедура обработки входящих СМС
    [xDrip-ESP32.ino]
2018-02-13 Добавлено описание новых СМС
2018-02-16 Версия 1.2.2 Исправлена процедура чтения СМС FORAMT_BT и USE_GSM
    [xDrip-ESP32.ino]
2018-03-07 Версия 1.2.3 Исправлена процедура работы с GSM-модемом Исправлена процедура запроса кода трансмиттера в режиме xBridge
    [xDrip-ESP32.ino]
2018-03-07 Исправлена верхняя крышка для прибора без GSM-модема
    [xDrip32-WiFi-Top2.stl]
2018-03-09 Версия 1.2.4 Оптимизация процедуры приема радиосигнала Увеличение минимального напряжения при использовании GSM-модема
2018-03-27 Версия 1.3.1 Добавлено чтение данных с плохим CRC
2018-04-01 Версия 1.3.2 Исправлена ошибка чтения "плохих" данных
    [xDrip-ESP32.ino]
2018-04-07 Новый вариант печатной платы
2018-05-12 Версия 1.3.3 Исправлена обработка смс BT_FORMAT и USE_GSM
    [xDrip-ESP32.ino]
2018-05-30 Версия 1.4.1 Работает сопряжение с телефоном XDrip+ по БТ
2018-09-14 Версия 4.1.2 Добавлена возможность очищать список привязанных BT устройств Добавены выходы по таймауту в процедуре выключения BT
2018-09-14 Исправлен текст Вэб-Формы
2018-09-15 Обновлены модели корпуса
    [xDrip32-3G-Bottom.stl, xDrip32-3G-Bottom3.stl, xDrip32-3G-Top.stl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]
2018-12-01 Версия 1.5.1 Добавлена обработка пакетов с некоректным CRC
2019-02-10 Версия 1.6.1 Пересобрано под SDK 3.x Режим xBridge НЕ РАБОТАЕТ
2019-02-10 Внесены изменения в Read.me
2019-03-01 Новые варианты корпусов
    [xDrip32-3G-Top3.stl, xDrip32-3G-Top4.stl, xDrip32-3G-Top5.stl]
2019-03-16 Весия 1.6.2 Добавлен механизм подстройки частоты радиомодуля.
2019-04-24 Версия 1.6.3 Небольшая ошибка при компиляции без ключа #define USE_FREQEST
